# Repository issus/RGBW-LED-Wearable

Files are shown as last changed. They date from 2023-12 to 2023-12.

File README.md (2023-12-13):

# Custom Programmable RGBW LED Wearable Board

Welcome to the repository for creating your own custom programmable RGBW LED wearable board! This project is perfect for enthusiasts in electronics, wearable tech, and DIY makers looking to add a vibrant touch to their creations.

## What's Inside

-   **Altium Design Files**: These files are the blueprint for your LED board. They include the schematics and PCB layout necessary to build the board from scratch.
-   **Source Code**: Dive into the pre-written code for controlling the LEDs. It's written for the Microchip ATTINY416 microcontroller, ensuring a blend of simplicity and functionality.
-   **Bill of Materials (BOM)**: A detailed list of all the components you'll need, including the Microchip ATTINY416, RGBW LEDs, resistors, and more.
-   **Programming Fixture**: A 3D printable fixture for easily programming batches of the boards.

## Features

-   **Compact Design**: Perfect for integrating into various wearables and small-scale projects.
-   **Microchip ATTINY416 Microcontroller**: A cost-effective yet powerful microcontroller at the heart of the design.
-   **RGBW LEDs**: Offers a broad spectrum of colors including a dedicated white LED for enhanced brightness and color mixing.
-   **Daisy Chain Capability**: Designed to connect multiple boards in a sequence for complex patterns and displays.
-   **Programming Flexibility**: Compatible with various programming environments, suitable for both beginners and experienced users.

----------

Happy creating, and light up your projects with your very own touch of LED brilliance! 🌟

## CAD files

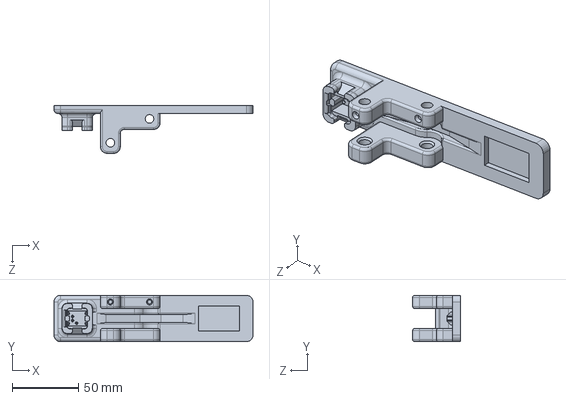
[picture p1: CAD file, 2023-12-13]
Programming Fixture/Fixture Base.SLDPRT
150.0 x 35.0 x 36.0 mm

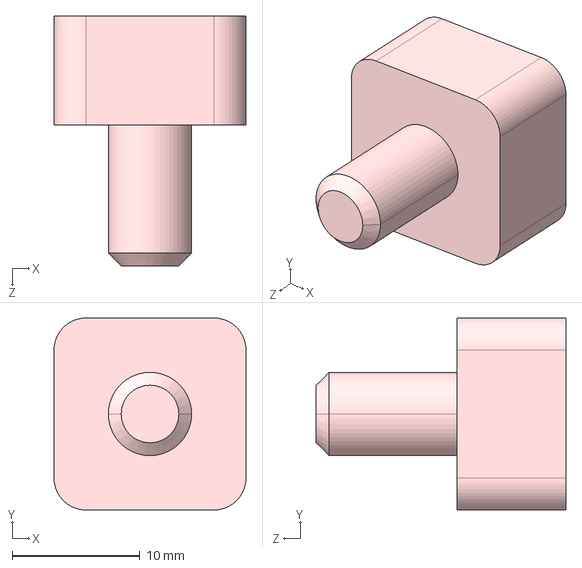
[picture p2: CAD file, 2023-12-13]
Programming Fixture/STEP/End Effector.STEP
15.0 x 15.0 x 19.5 mm

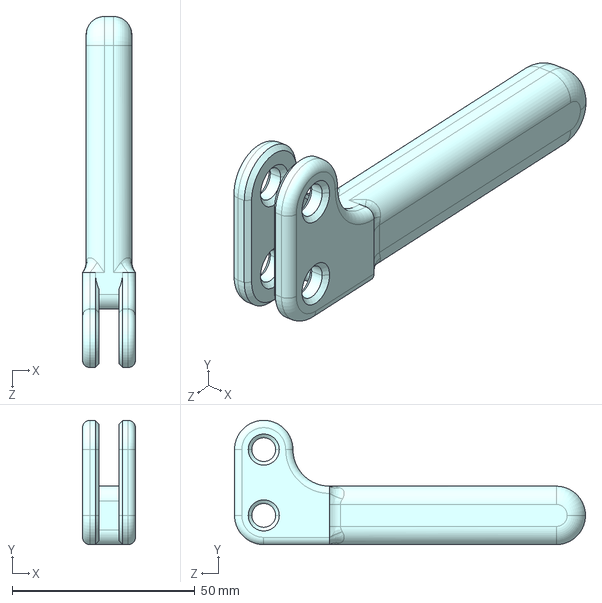
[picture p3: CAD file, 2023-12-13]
Programming Fixture/STEP/Handle.STEP
14.5 x 34.0 x 96.0 mm

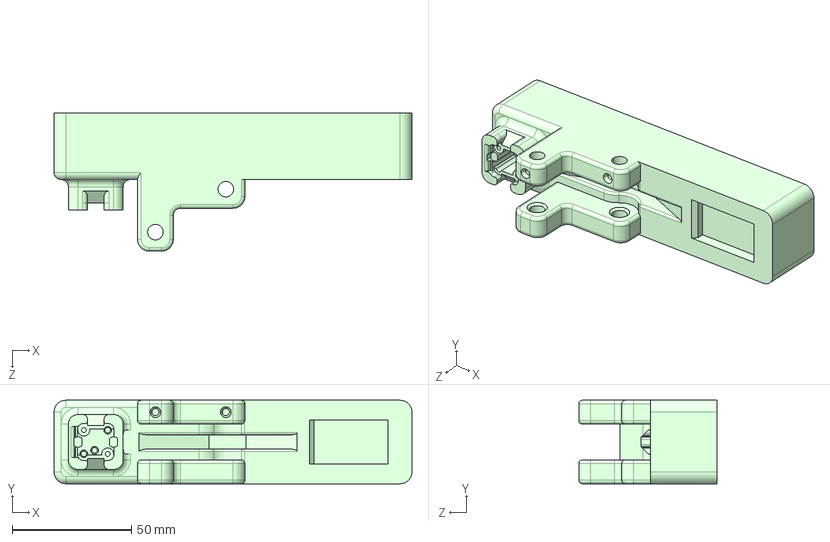
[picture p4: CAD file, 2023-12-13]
Programming Fixture/STEP/Long Fixture Base.STEP
150.0 x 35.0 x 58.0 mm

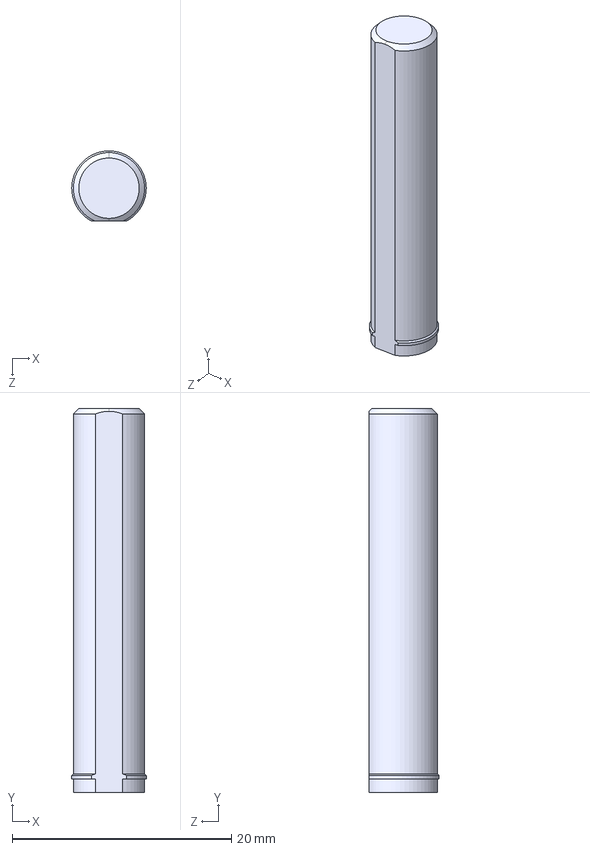
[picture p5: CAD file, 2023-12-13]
Programming Fixture/STEP/Dowel 35mm.STEP
6.80 x 35.0 x 6.40 mm

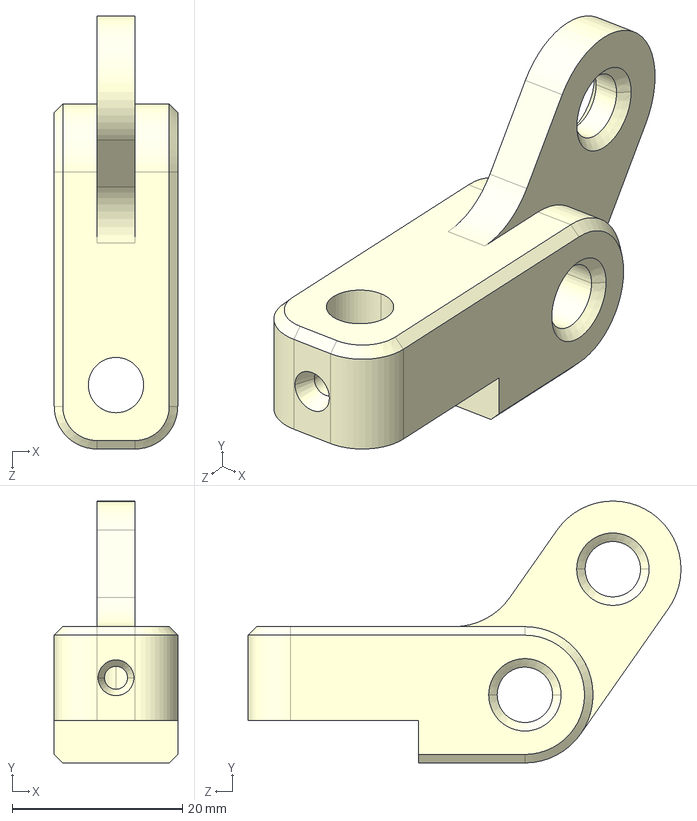
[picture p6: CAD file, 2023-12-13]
Programming Fixture/STEP/Press Linkage.STEP
14.5 x 30.7 x 50.8 mm

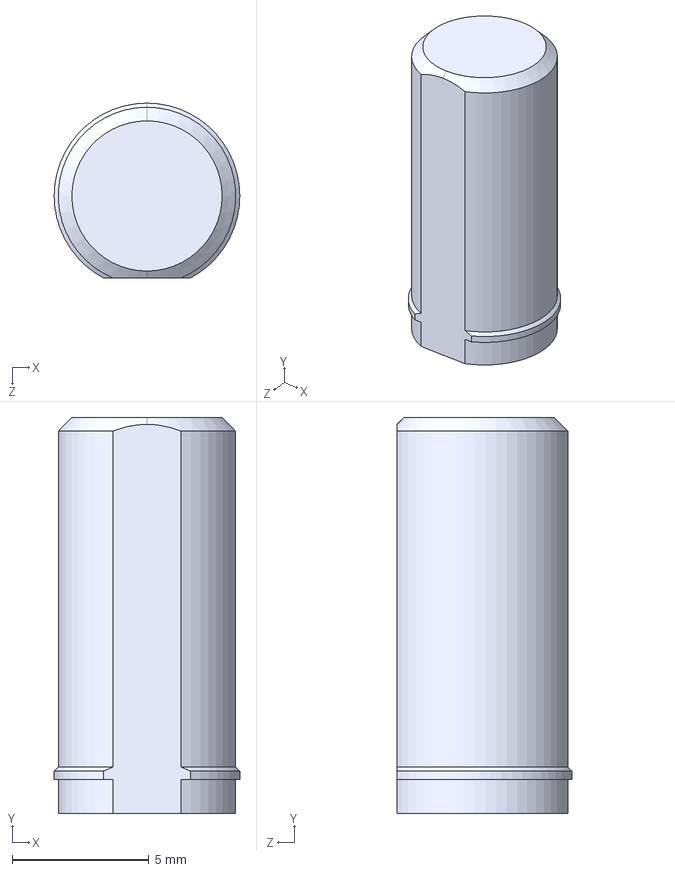
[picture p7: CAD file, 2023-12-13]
Programming Fixture/STEP/Dowel 14.5mm.STEP
6.80 x 14.5 x 6.40 mm

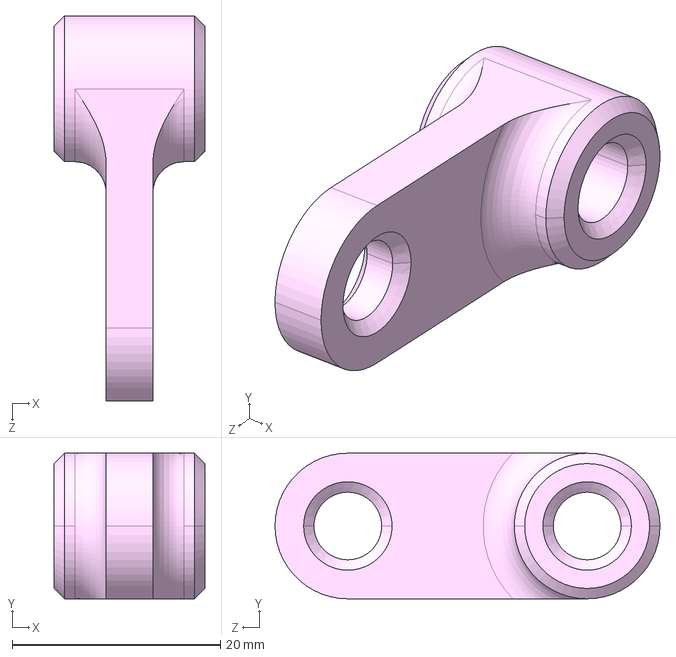
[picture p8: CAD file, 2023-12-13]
Programming Fixture/STEP/Lower Linkage.STEP
14.5 x 14.0 x 37.0 mm

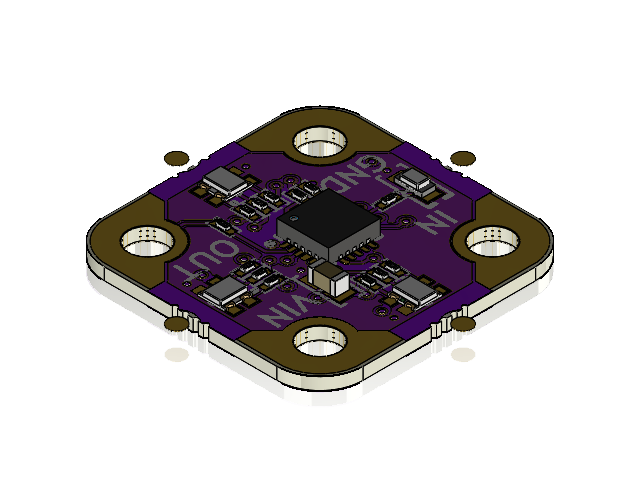
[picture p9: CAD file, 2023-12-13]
Programming Fixture/ETEX_-_Microcontroller_RGB.SLDASM
ETEX_-_Microcontroller_RGB_BOARD
RES_0201_0603_CR0201-JW-390GLF-1 x 6
RES_0201_0603_WR02X151_JAL-1 x 3
RES_0201_0603_WR02X10R0FAL-1
RES_0201_0603_WR02X3300FAL-1 x 2
RES_0201_0603_CR0201-JW-103GLF-1
MICROCHIP_VQFN-20_3X3_REB_ATTINY416-MFR-1
Harvatek_B38G3RGB-10D0003H2U1930_B38G3RGB-10D0003H2U1930-1 x 3
LED_0603_1608_B1931TW--20P000314U1930-1
CAP_0603_1608_GCM188R71E105KA64D-2
Top SolderMask_ETEX - Microcontroller RGB_0
Top SolderMask_ETEX - Microcontroller RGB_1
Top Layer_ETEX - Microcontroller RGB_0
Top Layer_ETEX - Microcontroller RGB_1
Top Layer_ETEX - Microcontroller RGB_2
Layer 1_ETEX - Microcontroller RGB_0
Layer 1_ETEX - Microcontroller RGB_1
Layer 2_ETEX - Microcontroller RGB_0
Layer 2_ETEX - Microcontroller RGB_1
Layer 2_ETEX - Microcontroller RGB_2
Bottom Layer_ETEX - Microcontroller RGB_0
Bottom Layer_ETEX - Microcontroller RGB_1
Bottom Layer_ETEX - Microcontroller RGB_2
Bottom Layer_ETEX - Microcontroller RGB_3
Bottom Layer_ETEX - Microcontroller RGB_4
Bottom Layer_ETEX - Microcontroller RGB_5
Bottom SolderMask_ETEX - Microcontroller RGB_0
Bottom SolderMask_ETEX - Microcontroller RGB_1
Interlayer_ETEX - Microcontroller RGB
Layer_ViaTop Layer-Bottom Layer_ETEX - Microcontroller RGB

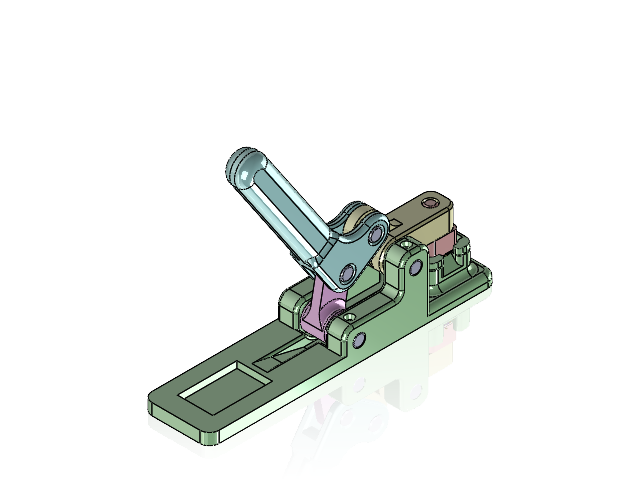
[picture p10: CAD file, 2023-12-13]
Programming Fixture/ASM-FIXTURE-Programming.SLDASM
ETEX_-_Microcontroller_RGB_BOARD
RES_0201_0603_CR0201-JW-390GLF-1 x 6
RES_0201_0603_WR02X151_JAL-1 x 3
RES_0201_0603_WR02X10R0FAL-1
RES_0201_0603_WR02X3300FAL-1 x 2
RES_0201_0603_CR0201-JW-103GLF-1
MICROCHIP_VQFN-20_3X3_REB_ATTINY416-MFR-1
Harvatek_B38G3RGB-10D0003H2U1930_B38G3RGB-10D0003H2U1930-1 x 3
LED_0603_1608_B1931TW--20P000314U1930-1
CAP_0603_1608_GCM188R71E105KA64D-2
Top SolderMask_ETEX - Microcontroller RGB_0
Top SolderMask_ETEX - Microcontroller RGB_1
Top Layer_ETEX - Microcontroller RGB_0
Top Layer_ETEX - Microcontroller RGB_1
Top Layer_ETEX - Microcontroller RGB_2
Layer 1_ETEX - Microcontroller RGB_0
Layer 1_ETEX - Microcontroller RGB_1
Layer 2_ETEX - Microcontroller RGB_0
Layer 2_ETEX - Microcontroller RGB_1
Layer 2_ETEX - Microcontroller RGB_2
Bottom Layer_ETEX - Microcontroller RGB_0
Bottom Layer_ETEX - Microcontroller RGB_1
Bottom Layer_ETEX - Microcontroller RGB_2
Bottom Layer_ETEX - Microcontroller RGB_3
Bottom Layer_ETEX - Microcontroller RGB_4
Bottom Layer_ETEX - Microcontroller RGB_5
Bottom SolderMask_ETEX - Microcontroller RGB_0
Bottom SolderMask_ETEX - Microcontroller RGB_1
Interlayer_ETEX - Microcontroller RGB
Layer_ViaTop Layer-Bottom Layer_ETEX - Microcontroller RGB
Pogo 16x1 Spear Head x 7
Fixture Base
Lower Linkage
Handle
Press Linkage
End Effector
Dowel 14.5mm x 2
Dowel 35mm x 2

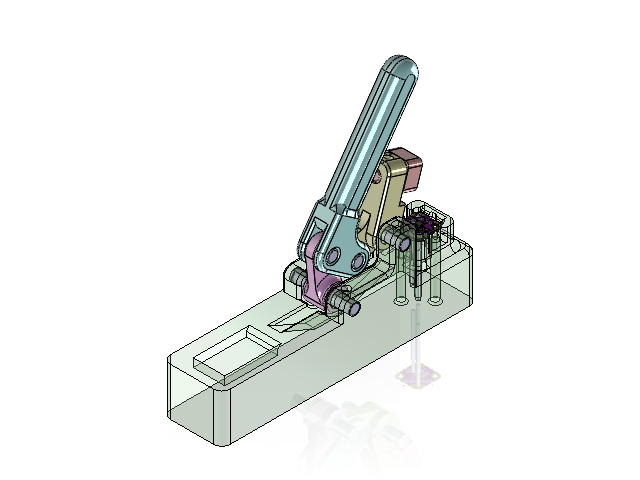
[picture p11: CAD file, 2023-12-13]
Programming Fixture/ASM-LONG-FIXTURE-Programming.SLDASM
ETEX_-_Microcontroller_RGB_BOARD
RES_0201_0603_CR0201-JW-390GLF-1 x 6
RES_0201_0603_WR02X151_JAL-1 x 3
RES_0201_0603_WR02X10R0FAL-1
RES_0201_0603_WR02X3300FAL-1 x 2
RES_0201_0603_CR0201-JW-103GLF-1
MICROCHIP_VQFN-20_3X3_REB_ATTINY416-MFR-1
Harvatek_B38G3RGB-10D0003H2U1930_B38G3RGB-10D0003H2U1930-1 x 3
LED_0603_1608_B1931TW--20P000314U1930-1
CAP_0603_1608_GCM188R71E105KA64D-2
Top SolderMask_ETEX - Microcontroller RGB_0
Top SolderMask_ETEX - Microcontroller RGB_1
Top Layer_ETEX - Microcontroller RGB_0
Top Layer_ETEX - Microcontroller RGB_1
Top Layer_ETEX - Microcontroller RGB_2
Layer 1_ETEX - Microcontroller RGB_0
Layer 1_ETEX - Microcontroller RGB_1
Layer 2_ETEX - Microcontroller RGB_0
Layer 2_ETEX - Microcontroller RGB_1
Layer 2_ETEX - Microcontroller RGB_2
Bottom Layer_ETEX - Microcontroller RGB_0
Bottom Layer_ETEX - Microcontroller RGB_1
Bottom Layer_ETEX - Microcontroller RGB_2
Bottom Layer_ETEX - Microcontroller RGB_3
Bottom Layer_ETEX - Microcontroller RGB_4
Bottom Layer_ETEX - Microcontroller RGB_5
Bottom SolderMask_ETEX - Microcontroller RGB_0
Bottom SolderMask_ETEX - Microcontroller RGB_1
Interlayer_ETEX - Microcontroller RGB
Layer_ViaTop Layer-Bottom Layer_ETEX - Microcontroller RGB
Long Fixture Base
Lower Linkage
Handle
Press Linkage
End Effector
Dowel 14.5mm x 2
Dowel 35mm x 2
Pogo 33x2 Spikey Head x 3

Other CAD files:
Programming Fixture/Dowel 14.5mm.SLDPRT
Programming Fixture/Dowel 35mm.SLDPRT
Programming Fixture/End Effector.SLDPRT
Programming Fixture/Handle.SLDPRT
Programming Fixture/Long Fixture Base.SLDPRT
Programming Fixture/Lower Linkage.SLDPRT
Programming Fixture/Press Linkage.SLDPRT
Programming Fixture/STL/Dowel 14.5mm.STL
Programming Fixture/STL/Dowel 35mm.STL
Programming Fixture/STL/End Effector.STL
Programming Fixture/STL/Handle.STL
Programming Fixture/STL/Long Fixture Base.STL
Programming Fixture/STL/Lower Linkage.STL
Programming Fixture/STL/Press Linkage.STL

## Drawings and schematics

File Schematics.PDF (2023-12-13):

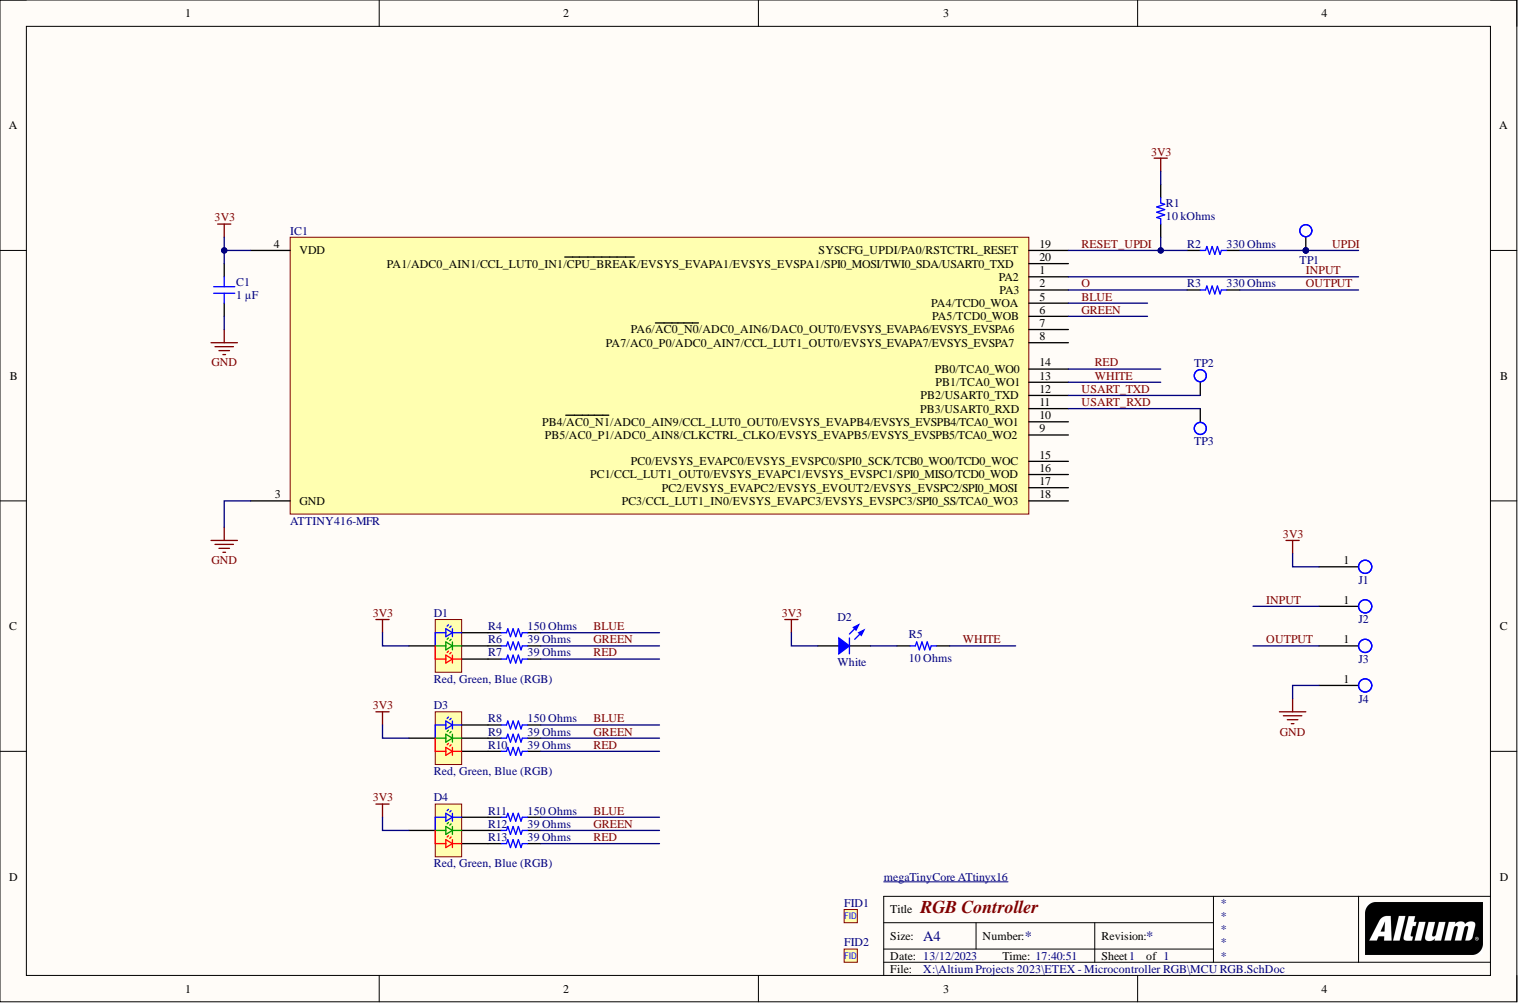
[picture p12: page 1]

Red, Green, Blue (RGB)

X:\Altium Projects 2023\ETEX - Microcontroller RGB\MCU RGB.SchDoc

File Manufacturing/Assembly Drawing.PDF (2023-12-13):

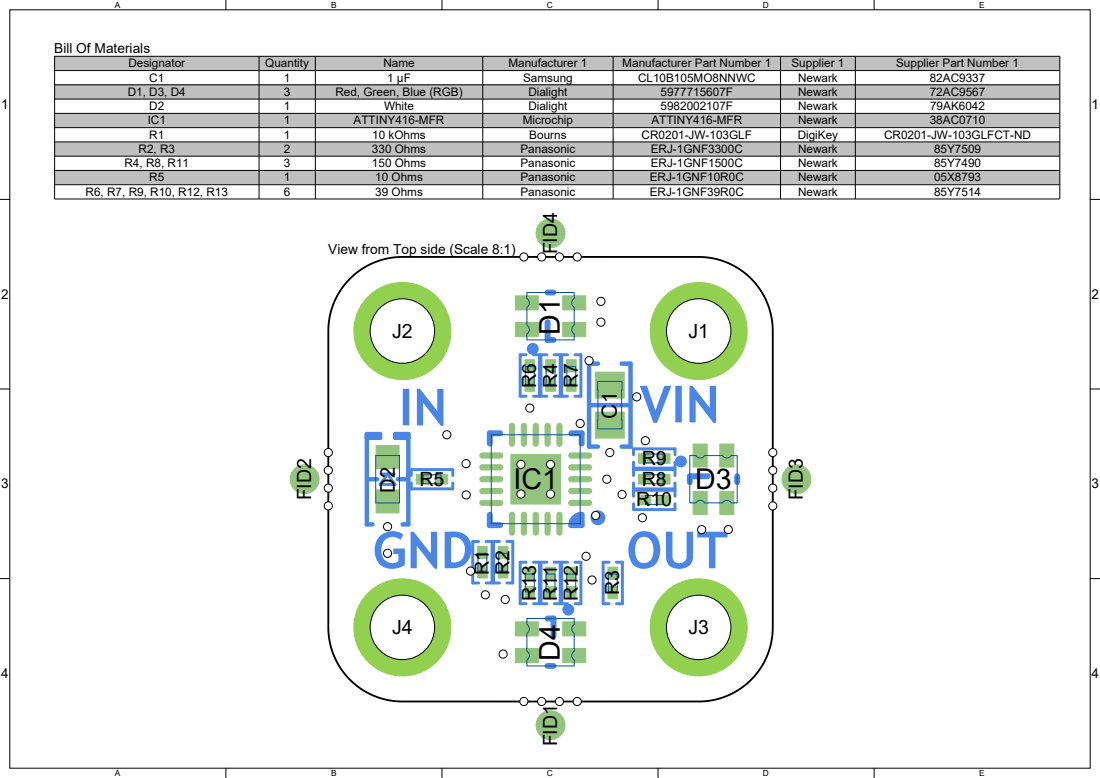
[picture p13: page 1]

Designator | Quantity | Name | Manufacturer 1 | Manufacturer Part Number 1 | Supplier 1 | Supplier Part Number 1
C1 | 1 | 1 µF | Samsung | CL10B105MO8NNWC | Newark | 82AC9337
D1, D3, D4 | 3 | Red, Green, Blue (RGB) | Dialight | 5977715607F | Newark | 72AC9567
D2 | 1 | White | Dialight | 5982002107F | Newark | 79AK6042
IC1 | 1 | ATTINY416-MFR | Microchip | ATTINY416-MFR | Newark | 38AC0710
R1 | 1 | 10 kOhms | Bourns | CR0201-JW-103GLF | DigiKey | CR0201-JW-103GLFCT-ND
R2, R3 | 2 | 330 Ohms | Panasonic | ERJ-1GNF3300C | Newark | 85Y7509
R4, R8, R11 | 3 | 150 Ohms | Panasonic | ERJ-1GNF1500C | Newark | 85Y7490
R5 | 1 | 10 Ohms | Panasonic | ERJ-1GNF10R0C | Newark | 05X8793

R6, R7, R9, R10, R12, R13 | 6 | 39 Ohms | Panasonic | ERJ-1GNF39R0C | Newark | 85Y7514

View from Top side (Scale 8:1)

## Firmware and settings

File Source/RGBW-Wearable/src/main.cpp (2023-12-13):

#include <Arduino.h>

int rPin = PIN_PB0;
int gPin = PIN_PA5;
int bPin = PIN_PA4;
int wPin = PIN_PB1;

int outPin = PIN_PA3;
int inPin = PIN_PA2;

//#define MODE_FADER 1 // fade all colours randomly
//#define MODE_FADESINGLE rPin // fade a single colour
#define MODE_CHAINSTARTER 1 // first microcontroller in a chain of chasing leds, which will generate the starting pulse
#define MODE_CHASING 1 // chasing leds, does one flash after receving a high input pulse

//                0bRGBW mask
#define MASK_FADE 0b1111 // which colours to use for fading

int min = 127;
int max = 255;

int minMod = 1;
int maxMod = 20;

int pins[] = { rPin, gPin, bPin, wPin };

// Create an array to store available pins based on the mask
int availablePins[4];
int availableCount = 0;

uint32_t generateRandomSeed();
void fadeAll();
void fadeSingleCh(int);
void fadeTwoCh(int, int);
void fadeRandom();

void toggleOut();

void allLedsOff();

uint8_t inputActive();

void setup() {
  // enable randomisation
  randomSeed(generateRandomSeed());

  pinMode(inPin, INPUT_PULLUP);
  pinMode(outPin, OUTPUT);

  digitalWrite(outPin, 1);

  // set all LEDs off
  allLedsOff();

  // Check each pin against the mask
  for (int i = 0; i < 4; i++) {
    if (MASK_FADE & (1 << 3 - i)) {
      availablePins[availableCount++] = pins[i];
    }
  }

  // cycle through each allowable LED and flash it to check it is functioning
  for (int i = 0; i < availableCount; i++)
  {
    analogWrite(availablePins[i], min); // led on
    delay(200);
    analogWrite(availablePins[i], max); // led off
  }

  #ifdef MODE_CHAINSTARTER
    delay(600); // give all other microcontrollers in the chain to finish bootup sequence
    toggleOut();
  #endif
}

void loop() {
  while (true) {
    #ifdef MODE_FADER
      fadeRandom();
    #endif

    #ifdef MODE_FADESINGLE
      fadeSingleCh(MODE_FADESINGLE);
    #endif

    #ifdef MODE_CHASING
      if (inputActive())
      {
        fadeRandom();

        toggleOut();
      }
    #endif

  }
}

/// @brief Debounced check if input has a signal
/// @return true if input remains low for 5ms
uint8_t inputActive()
{
  if (!digitalRead(inPin)) {
    for (int i = 0; i < 5; i++) {
      if (digitalRead(inPin)) return 0;

      delay(1);
    }

    return 1;
  }

  return 0;
}

/// @brief Toggle the output pin
void toggleOut() {
  digitalWrite(outPin, 0);
  delay(20);
  digitalWrite(outPin, 1);
}

/// @brief fades a random channel or channels of LEDs
void fadeRandom() {
  int rnd = random(0, 10);

  if (rnd >= 5 && rnd <= 7) {
    fadeAll();
  }
  else if (rnd > 8 && availableCount > 1) {
    // Select two random pins from the available pins
    int pin1 = availablePins[random(0, availableCount)];
    int pin2;

    do {
      pin2 = availablePins[random(0, availableCount)];
    } while (pin1 == pin2); // Ensure two different pins are selected

    fadeTwoCh(pin1, pin2);
  }
  else {
    fadeSingleCh(availablePins[random(0, availableCount)]);
  }
}

/// @brief Fades up and down using available LEDs based on the mask
void fadeAll() {
  // Create arrays for the values and modifiers of the available pins
  int values[availableCount];
  int modifiers[availableCount];

  // Initialize random values and modifiers for each available pin
  for (int i = 0; i < availableCount; i++) {
    values[i] = random(min, max);
    modifiers[i] = random(minMod, maxMod);
  }

  // fade for about 1.8 seconds
  for (int i = 0; i < 60; i++) {
    for (int j = 0; j < availableCount; j++) {
      // Check and modify the fade direction if limits are reached
      if (values[j] >= max - maxMod) modifiers[j] = -random(minMod, maxMod);
      if (values[j] <= min + maxMod) modifiers[j] = random(minMod, maxMod);
      
      // Apply the modifier
      values[j] += modifiers[j];

      // Write the new value to the LED
      analogWrite(availablePins[j], values[j]);
    }
    // wait for 30 milliseconds to see the dimming effect
    delay(30);
  }

  allLedsOff();
}

/// @brief Fades a single LED up then down
/// @param pin LED channel to fade
void fadeSingleCh(int pin) {
  int chMod = random(minMod,maxMod);

  int ch = min;
  
  for (int i = 0; i < 80 && ch <= max - maxMod; i++)
  {
    if (ch >= max - maxMod) chMod = -random(minMod, maxMod);
    if (ch <= min + maxMod) chMod =  random(minMod, maxMod);
    
    ch += chMod;

    analogWrite(pin, ch);
    delay(30);
  }

  allLedsOff();
}

/// @brief Fades using two channels to make a mixed colour
/// @param pin1 First LED pin to use
/// @param pin2 Second LED pin to use
void fadeTwoCh(int pin1, int pin2) {
  if (pin1 == pin2) {
    fadeSingleCh(pin1);
    return;
  }

  int ch1 = min;
  int ch2 = random(min, max);
  
  int ch1Mod = random(minMod,maxMod);
  int ch2Mod = random(minMod,maxMod);
  
  for (int i = 0; i < 80 && ch1 <= max - maxMod; i++)
  {
    if (ch1 >= max - maxMod) ch1Mod = -random(minMod, maxMod);
    if (ch1 <= min + maxMod) ch1Mod =  random(minMod, maxMod);
    if (ch2 >= max - maxMod) ch2Mod = -random(minMod, maxMod);
    if (ch2 <= min + maxMod) ch2Mod =  random(minMod, maxMod);

    ch1 += ch1Mod;
    ch2 += ch2Mod;

    analogWrite(pin1, ch1);
    analogWrite(pin2, ch2);
    
    delay(30);
  }

  allLedsOff();
}

/// @brief Turn off all leds (set PWM to max)
void allLedsOff() {
  for (int i = 0; i < availableCount; i++)
  {
    analogWrite(availablePins[i], max); // led off
  }
}

// from: https://rheingoldheavy.com/better-arduino-random-values/
uint32_t generateRandomSeed()
{
  uint8_t  seedBitValue  = 0;
  uint8_t  seedByteValue = 0;
  uint32_t seedWordValue = 0;
 
  for (uint8_t wordShift = 0; wordShift < 4; wordShift++)     // 4 bytes in a 32 bit word
  {
    for (uint8_t byteShift = 0; byteShift < 8; byteShift++)   // 8 bits in a byte
    {
      for (uint8_t bitSum = 0; bitSum <= 8; bitSum++)         // 8 samples of analog pin
      {
        seedBitValue = seedBitValue + (analogRead(PIN_PA6) & 0x01);                // Flip the coin eight times, adding the results together
      }
      delay(1);                                                                    // Delay a single millisecond to allow the pin to fluctuate
      seedByteValue = seedByteValue | ((seedBitValue & 0x01) << byteShift);        // Build a stack of eight flipped coins
      seedBitValue = 0;                                                            // Clear out the previous coin value
    }
    seedWordValue = seedWordValue | (uint32_t)seedByteValue << (8 * wordShift);    // Build a stack of four sets of 8 coins (shifting right creates a larger number so cast to 32bit)
    seedByteValue = 0;                                                             // Clear out the previous stack value
  }
  return (seedWordValue);
}
